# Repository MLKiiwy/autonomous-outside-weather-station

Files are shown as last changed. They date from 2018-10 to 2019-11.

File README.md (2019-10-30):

# Autonomous outside weather station

Build a complete autonomous outside weather station that can stay for years without battery change in your garden.
The station communicate the weather data to your home server OR a web server.
You can at any time access the graphs and last sensors values, from a web interface (smartphone compatible).

Total estimated cost of the full station: 40 euros.

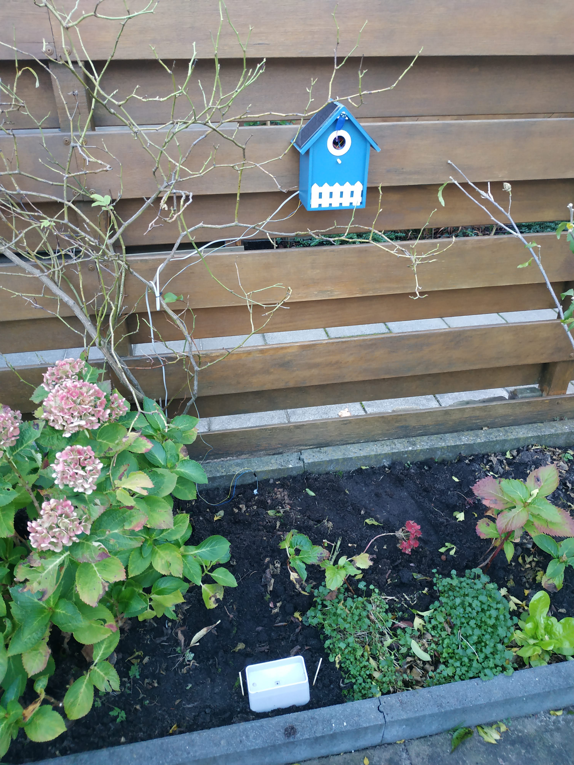
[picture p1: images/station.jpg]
Module Station setup outside

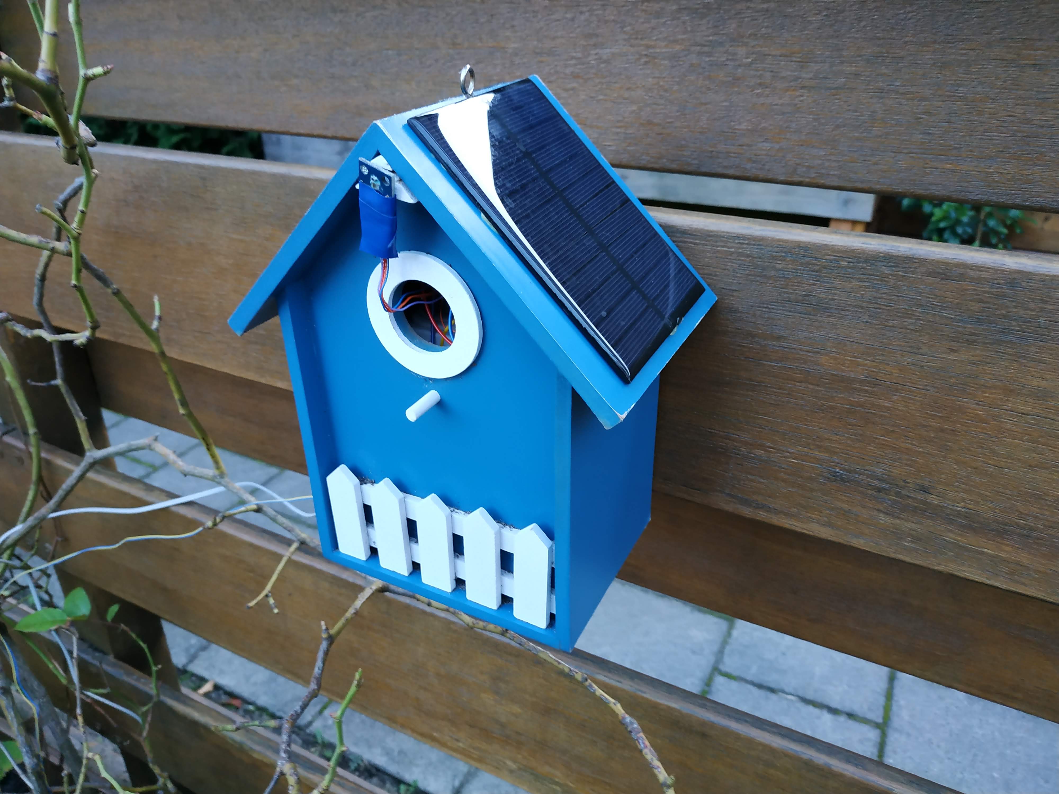
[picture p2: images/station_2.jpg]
Module Station setup outside 2


# Elements

Here is the detailed list of logical elements that compose the station.

## Station 

The station is build to be outside.
For that I use a small bird house.

Estimated cost: 5 euros

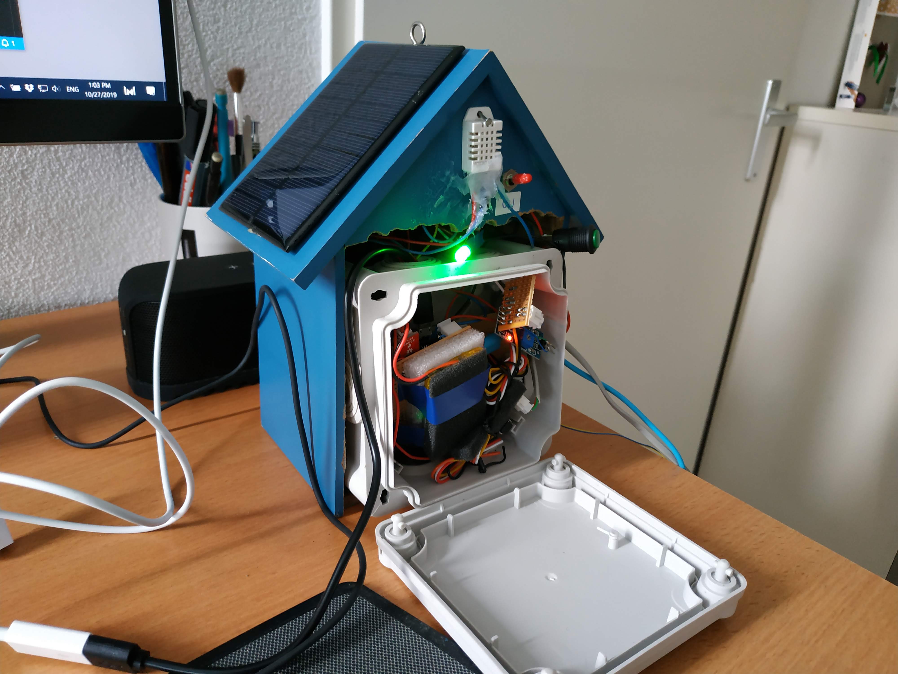
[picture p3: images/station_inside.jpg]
Module Station inside


## Main card with Wifi communication

The main card consist only of a ESP8266 + multiple connexions to each modules.
And for easy on/off, I have put a switch and a LED between the power module and the ESP8266.

Estimated cost: 3 euros

### Special Wire for DeepSleep

I use the deep sleep feature to save more power, and only take values every 10 minutes.

For that : Connect D0 to RST and use the deepSleep method in the code.

### Wifi Manager

You can install it from the library manager in arduino IDE
- [Wifi Manager] (https://github.com/tzapu/WiFiManager)

### MQTT

You can install it from the library manager in arduino IDE
- [PubSubClient] (https://github.com/knolleary/pubsubclient)

## Power module (Solar powered battery with level via I2C)

This module provide 4 outputs, 2 for power (+3.7V/GND) and 2 for battery level (I2C).
The battery is continuously charged by solar panel, with surcharge protection.
This module is autonomous and can be reuse in some other ESP8266 project.

[Detailed infos (Build instructions, components, sample code)](./elements/power_module/README.md)

## Rain counter module (Autonomous + low power consumption)  

This module provide a 5 pin interface: 2 for power (+3.7V/GND), 1 for waking up the module, 2 for communication (I2C)
This module should count the number of millimeter of rain. (precision 0.5 mm)
With a low power and complete autonomy even if main card is in sleep mode.

[Detailed infos (Build instructions, components, sample code)](./elements/rain_counter_module/README.md)

## Temperature and humidity sensor

This module you can read the outside temperature and humidity.
This module provide a 3 pin interface: 2 for power (3.7V/GND), 1 for reading the data.

[Detailed infos (Build instructions, components, sample code)](./elements/temperature_humidity_sensor/README.md)

## Atmospheric Pressure (+ station inside temperature and altitude)

This module provide atmospheric pressure, the temperature and the altitude.
This module is soldered directly on the main card with the ESP8266. (not autonomous, cannot be replace)

[Detailed infos (Build instructions, components, sample code)](./elements/barometric_sensor/README.md)

## Moisture sensor (or Hygrometer)

This module you can read the humidity of the soil with a probe.
This module provide a 4 pin interface (2 for power (3.7V/GND), 1 for waking up the module, 1 for com/reading)

[Detailed infos (Build instructions, components, sample code)](./elements/moisture_sensor/README.md)

## Light level sensor (Sun sensor)

This module you can read the level of the sun light (in lux)
This module provide a 4 pin interface: 2 for power (3.7V/GND), 2 for communication (I2C)

[Detailed infos (Build instructions, components, sample code)](./elements/light_level_sensor/README.md)

## Web Interface (Running on a home server)

I use Node-Red with the plugin for web UI.

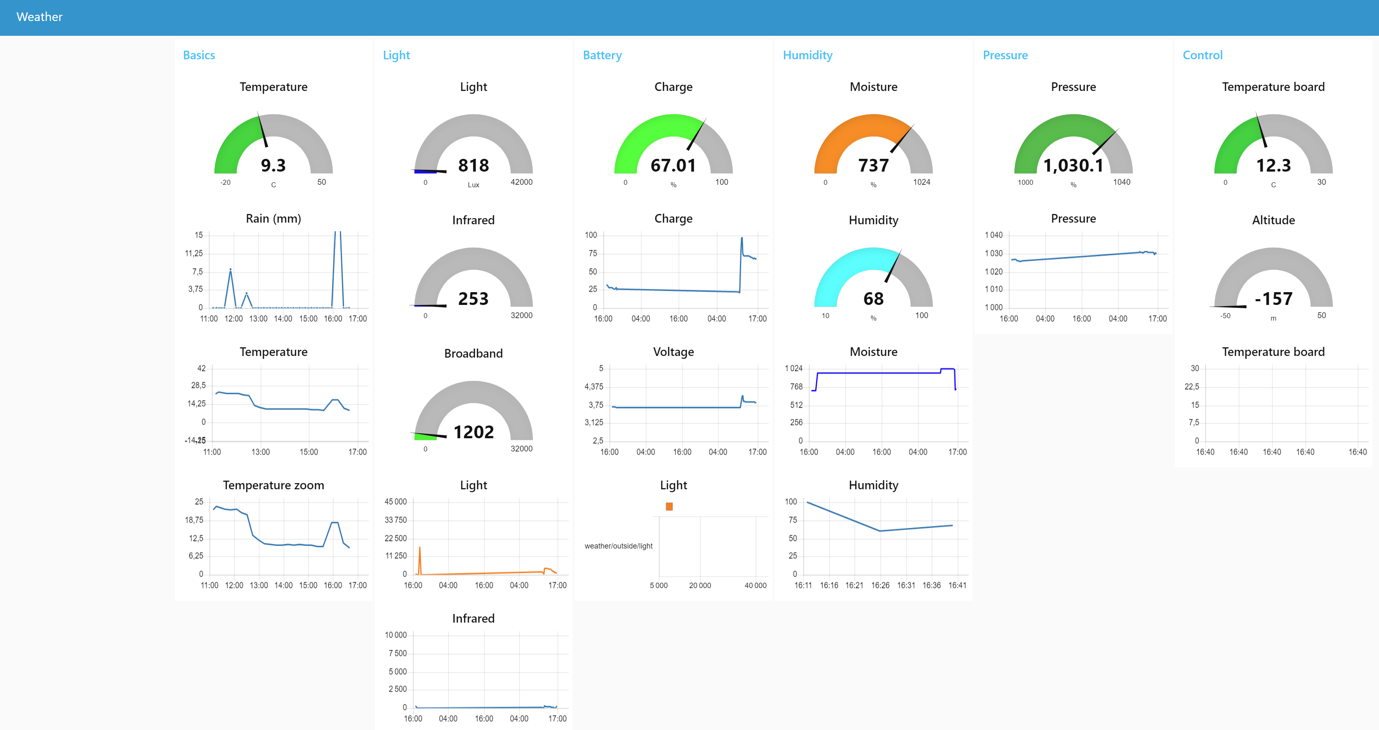
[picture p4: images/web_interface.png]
Module Web interface


## Install MQTT Broker on rapsberry Pi

See https://www.instructables.com/id/How-to-Use-MQTT-With-the-Raspberry-Pi-and-ESP8266/

```
sudo apt-get update
sudo apt-get upgrade
sudo apt-get install mosquitto -y
sudo apt-get install mosquitto-clients -y
```
## Final programs

See [Final program](./src/main.ino)

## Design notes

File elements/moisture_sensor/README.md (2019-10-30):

# Module : Soil Moisture Sensor

With this module you can read the humidity of the soil. 
For that we use a couple YL-38/YL-69.

## Corrosion / oxidation issue solution

If you use a soil moisture sensor before, if the sensor is powered for a long time, the probe is going to be oxided. 

So to avoid corrosion / oxidation we will power up the sensor only when reading, using a NPN Transistor (BC547) as switch.

## Images

### Module alone

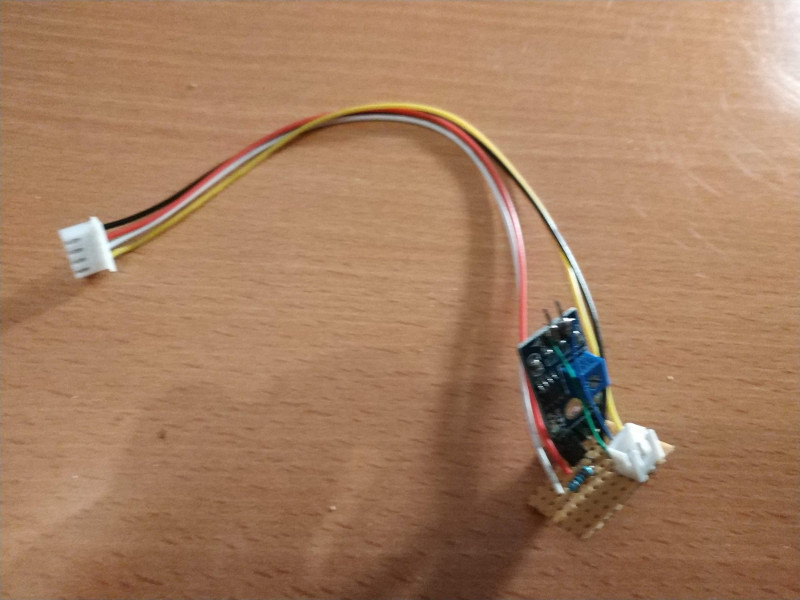
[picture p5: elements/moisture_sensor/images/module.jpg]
Module


### Module connected to all elements

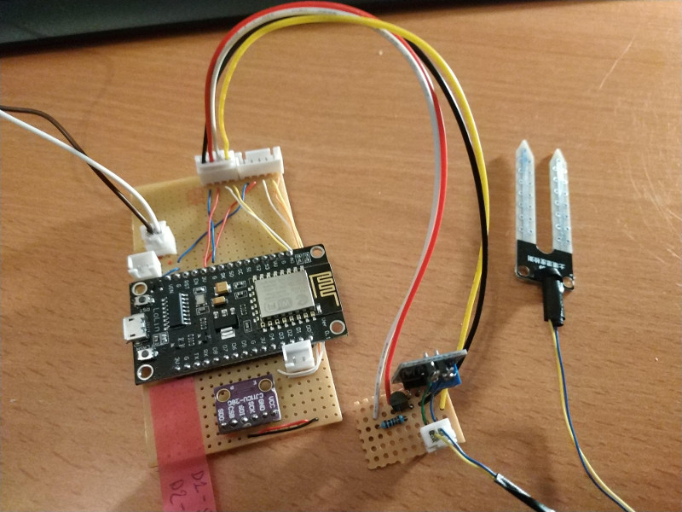
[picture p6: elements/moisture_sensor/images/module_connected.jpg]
Module connected


## Input

- 1 * 2 Pin for soil probe (YL-69)

## Output
- 1 * 4 Pin ( (Vin / GND / Reading Pin / Power On)

## Components 

- 1 hygrometer detection YL-69/YL-38 + (1euro)
- 1 transistor NPN BC547C (0.5 euro)
- 1 1 KOhm resistor ( 0.1 euro )

- some bakelite plate and thin wires (1 euro)

Estimated cost around 2.60 euros

## Schema

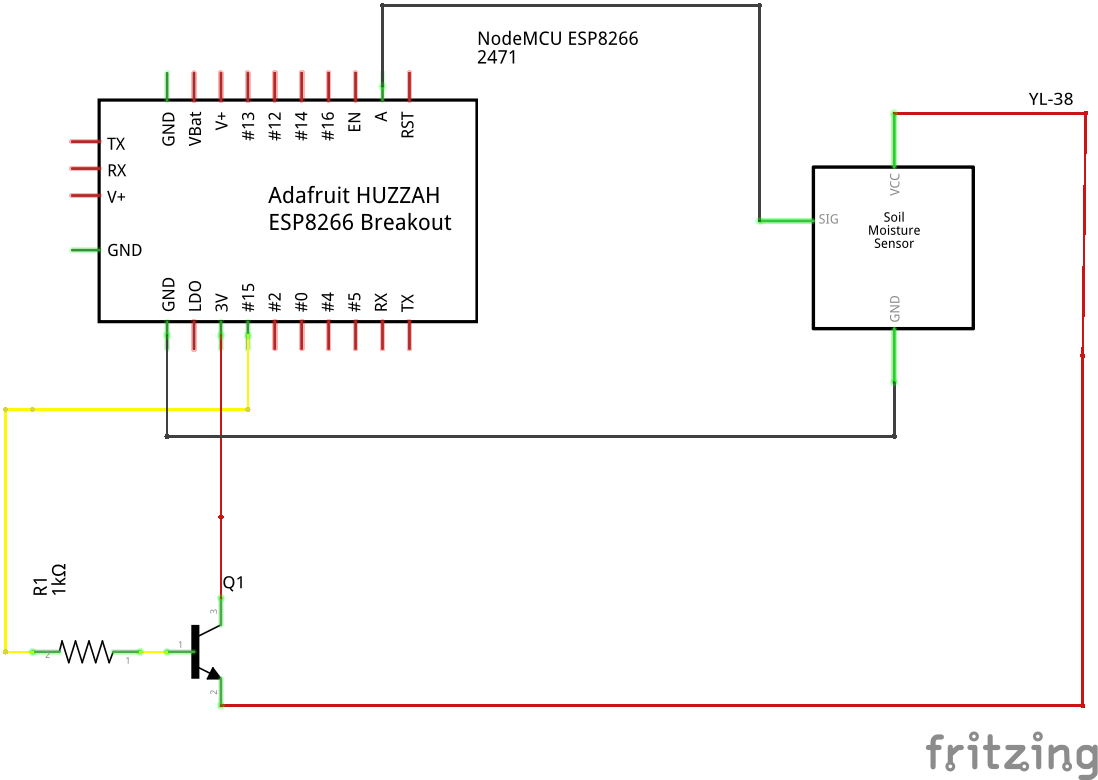
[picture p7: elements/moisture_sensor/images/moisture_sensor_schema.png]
Power module schema


## Required libraries 

[YL-38/YL-69 Sensor Arduino lib](https://github.com/jonson/arduino-moisture-sensor)

Execute [install.sh](./scripts/install.sh)

Or : 

```bash
git clone git@github.com:jonson/arduino-moisture-sensor.git
mv arduino-moisture-senso/libraries/ ~/Arduino/libraries
```

## Tests 

Use the code [Reading moisture](./read_moisture_sensor/read_moisture_sensor.ino) to test the module.
This code will just continuously ask the module the value of humidity of the soil.

### Issues

Don't use PIN D4 (GPIO 2) for the reading Pin.
There is an issue with this Pin if your ESP8266 goes to deepsleep, it remains the pin High ...
I use the GPIO 12 (D6) with no issue in deep sleep (The state remains low)

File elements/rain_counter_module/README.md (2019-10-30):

# Module : Rain counter

This module should count the number of millimeter of rain. 
With a low power and complete autonomy even if main card is in sleep mode.

## Images

### Module alone

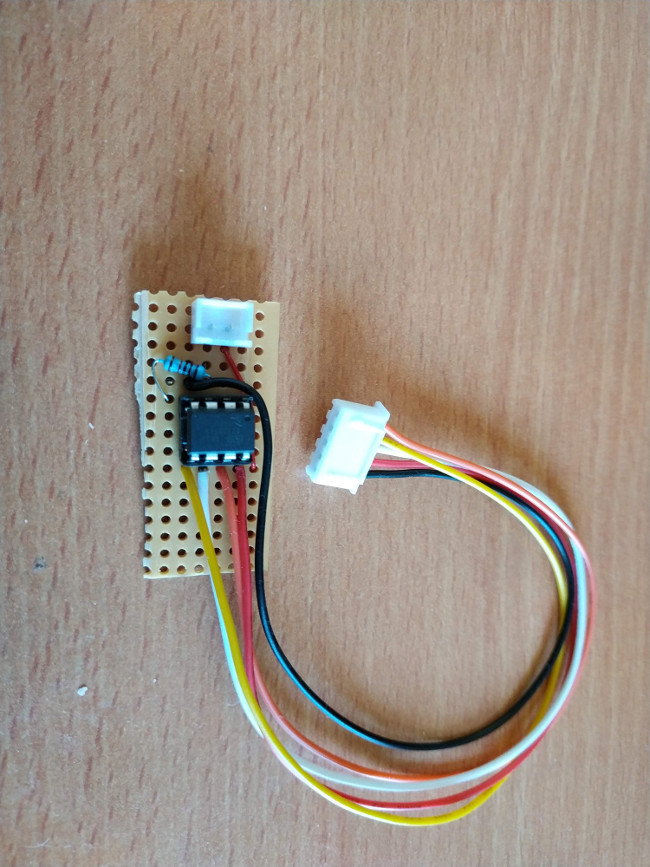
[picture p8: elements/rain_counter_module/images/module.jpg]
Module


### Module connected to all elements

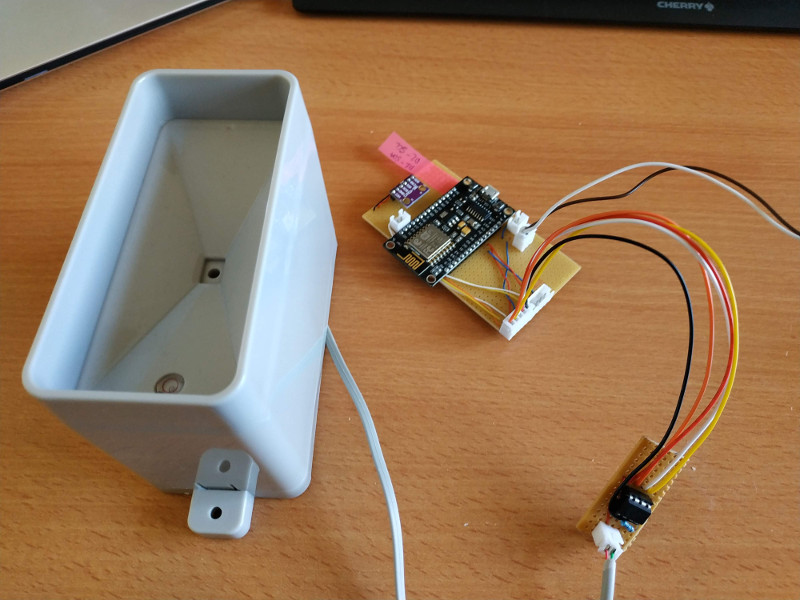
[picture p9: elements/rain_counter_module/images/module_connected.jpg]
Module connected


## Input

- 1 * 2 pin from rain collector

## Output

- 1 * 5 pin (Vin 3V, GND, 1 Wake up pin, 1 SDA, 1 SCL)

## Components 

- 1 rain collector (see [Rain meter/ rain gauge/ weather station spare part](https://www.aliexpress.com/item/1-pcs-of-spare-part-for-weather-station-for-rain-meter-to-measure-the-rain-volume/32793367115.html) - around 10 euros)
- 1 resistor (0.1 euros)
- 1 ATTiny85 (1 euro)

- some bakelite plate and thin wires (1 euro)

Estimated cost around 12.10 euros

## Using a pre-built rain collector

For that we use a pre-built rain collector from a commercial weather station.
This module is simply a rain collector that emit close a circuit, for each half millimeter collected. 
Its exactly the same behavior if you press a push button for every millimeter of rain.

Note: my rain collector has a surface of 0.0055 m2.
1mm of rain = 1Liter/m2 so here to have 1mm, you need 5.5ml.

During my test, I discover that my rain collector close the circuit twice for each millimeter, so the precision is of 0.5mm.

## Use a ATTiny as an autonomous module to count signal from rain collector

Because our station is going to sleep most of the time, we doesn't want to listen this signal from the ESP8266.

Instead we use a ATTiny85 as a "counter".
This tiny ship will listen this signal and increment a counter in its own memory.
Regulary the ESP8266 will ask the ATTiny the current value, and in the same time reset the value.

## Save more power => Put ATTiny85 in sleep mode and use an interuption

To save more power, we also use the "interupt" feature of the ATTiny85.
So when a signal is receive, the ATTiny count from the interuption function even in sleep mode (low power).
When the ESP8266 want to ask via I2C the rain count, before it put to high a wake up pin on the ATTiny and after send the I2C request.

## Schema

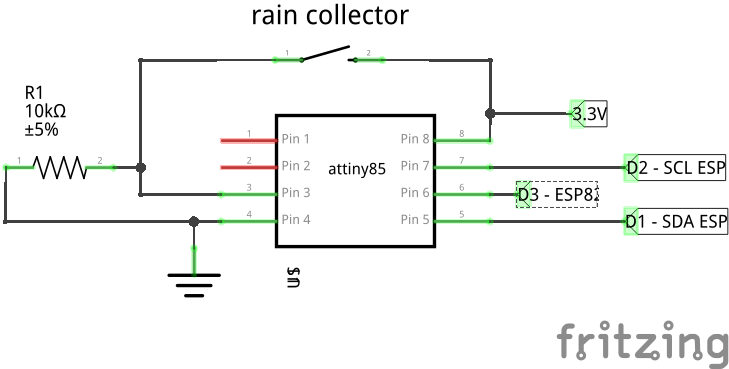
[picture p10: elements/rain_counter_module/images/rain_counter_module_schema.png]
Rain counter module schema


See also the pinout of the ATTiny85

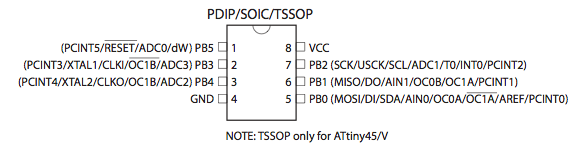
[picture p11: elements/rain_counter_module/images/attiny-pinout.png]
ATTiny85 pinout


## Required libraries 

Execute [install.sh](./scripts/install.sh) 

Or install them manually in your Arduino Lib directory.

### ATTiny85 support for Arduino

In board manager of Arduino find "ATTiny" lin and install it.

Required additional url in package manager : https://raw.githubusercontent.com/damellis/attiny/ide-1.6.x-boards-manager/package_damellis_attiny_index.json
More instructions [here](https://www.hackster.io/arjun/programming-attiny85-with-arduino-uno-afb829) .

### TinyWireS: AtTiny85 I2C Library

This [lib](https://github.com/nadavmatalon/TinyWireS) is used to make the ATTiny85 a slave on I2C.

Don't use the last version, there is an issue.
Use the one [here](./libs/TinyWireS).

## How to program the ATTiny85 ? 

See this good tutorial on [Hacktser](https://www.hackster.io/arjun/programming-attiny85-with-arduino-uno-afb829) 
I did exactly the same, I recommend to build a shield for programming the ATTiny85 with a "ZIF Socket".

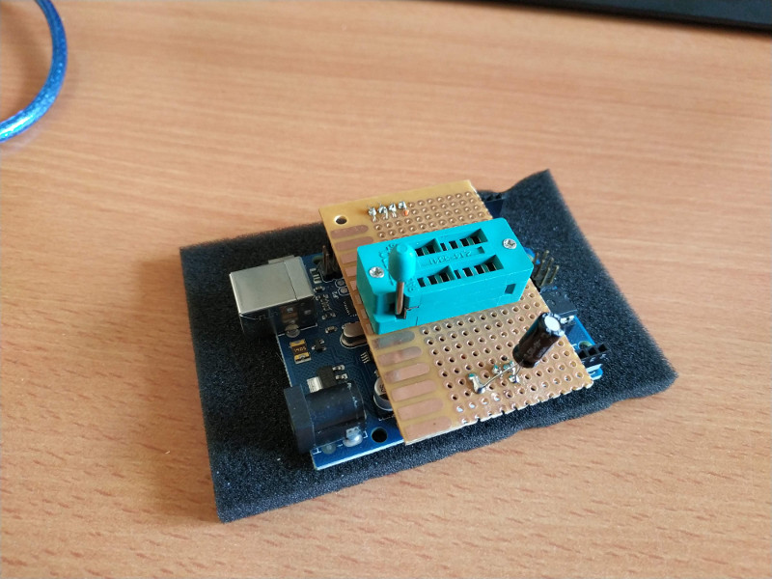
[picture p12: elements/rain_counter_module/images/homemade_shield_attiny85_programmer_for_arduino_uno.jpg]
Homemade ATTiny85 programmer shield for Arduino Uno


## Tests and development

For doing this module, I did a lot of small steps to test how to use the ATTiny85.
You can see all this step in order in the [./src](./src) folder.

### 1 - Try just to program the ATTiny85 with Arduino UNO + homemade shield

A simple program to blink the a LED.

### 2 - Do a communication with I2C between Arduino UNO and ATTiny85

Increase internal variable and return its value on each Arduino I2C request.

### 3 - Listen Interupt pin to count on ATTiny

### 4 - Interupt count + I2C communication 

### 5 - Interupt count + sleep + I2C Communication (Final ATTiny program)

### 6 - Final example using ESP8266 instead of Arduino Uno

## Issue with rain count not corresponding to number of closing on the rain collector

There is a difference between the number of tap of the rain collector, and what give the ATTiny85.
After several measure, I have decide to apply this formula to get the closest right value:

```c
ceil(value /10)
```

Of course it's an hack, I suppose the signal when the collector close the circuit create some "Jumps".
A way to fix it will be to clear the signal, maybe with a capacitor?

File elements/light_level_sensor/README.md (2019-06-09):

# Module : Light level sensor

With this module you can know the level of light. 
Usefull if you couple this data with the level of the power module, you can see normally when the solar panel are the most efficient.
For that we use a TSL2561 sensor.

## Images

### Module alone

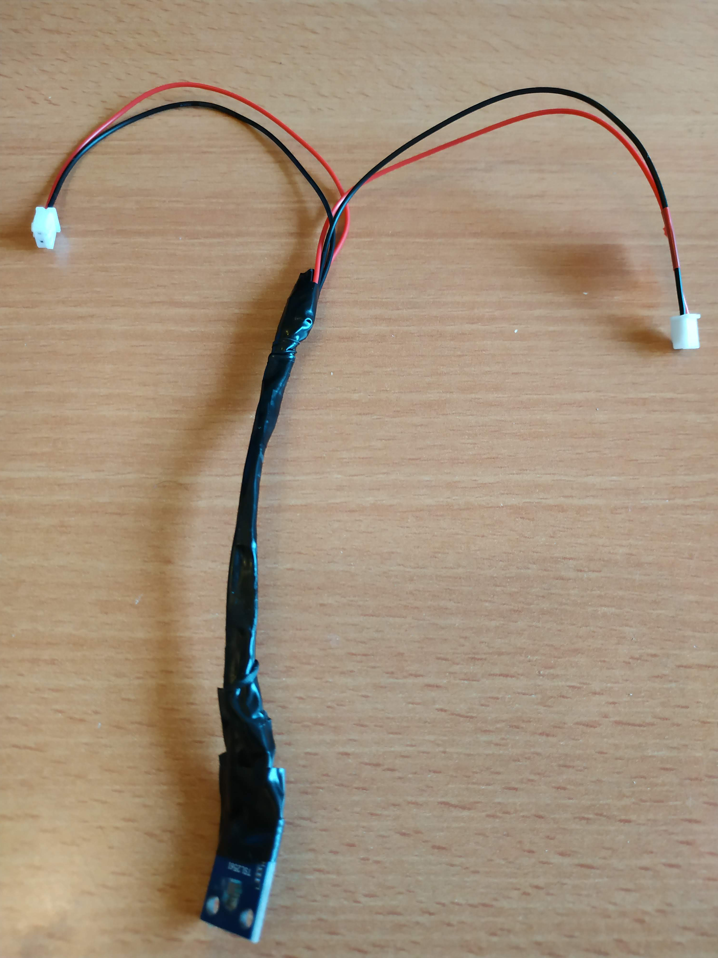
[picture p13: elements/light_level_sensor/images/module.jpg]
Module


### Module connected to all elements

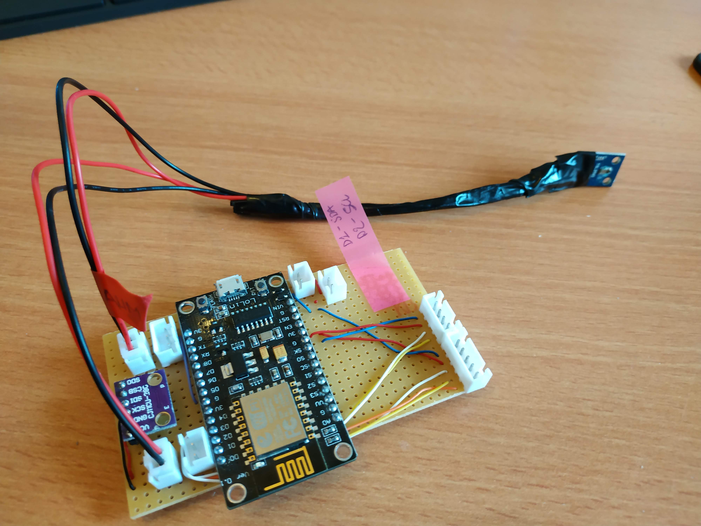
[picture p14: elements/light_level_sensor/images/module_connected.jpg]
Module connected


## Output

- 1 * 2 Pin ( (Vin 3.3v / GND)
- 1 * 2 Pin ( (SDA / SCL)

## Components

- 1 sensor TSL2561

Estimated cost around 2 euro

## Schema

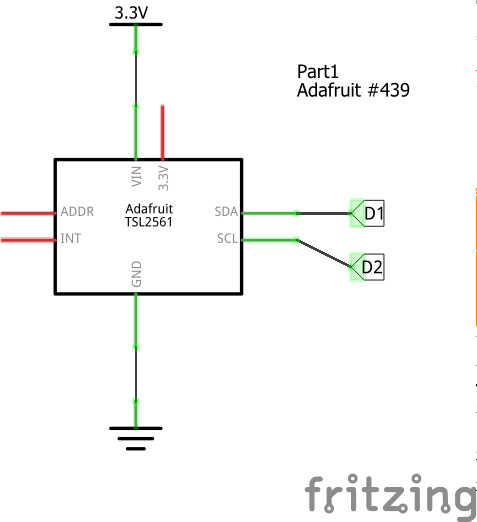
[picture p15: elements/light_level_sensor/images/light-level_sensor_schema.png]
Light level sensor


## Required libraries 

You can install it from the library manager in arduino IDE
- [Adafruit Unified Sensor] (https://github.com/adafruit/Adafruit_Sensor)
- [Adafruit TSL2561 (by Adafruit)](https://github.com/adafruit/Adafruit_TSL2561)

## Tests 

Use the code [Reading light level](./read_light-level_sensor.ino) to test the module.
This code will just continuously ask the module the value of the light level.

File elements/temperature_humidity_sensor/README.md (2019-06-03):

# Module : Temperature and humidity sensor

With this module you can read the temperature and humidity of the external air.
For that we use a DHT22 sensor.

## Images

### Module alone

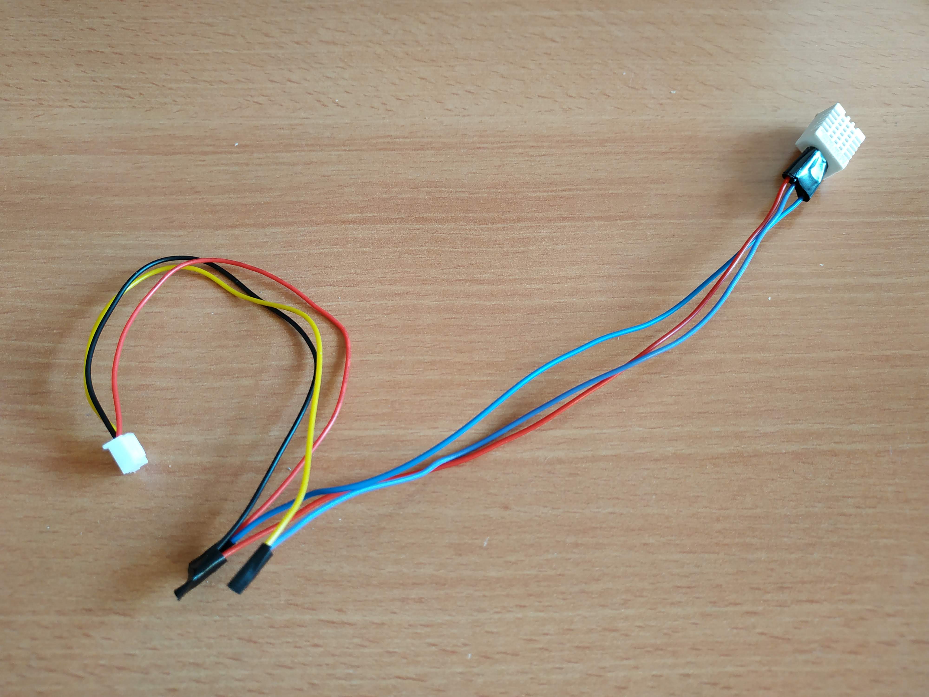
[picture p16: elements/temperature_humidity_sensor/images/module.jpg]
Module


### Module connected to all elements

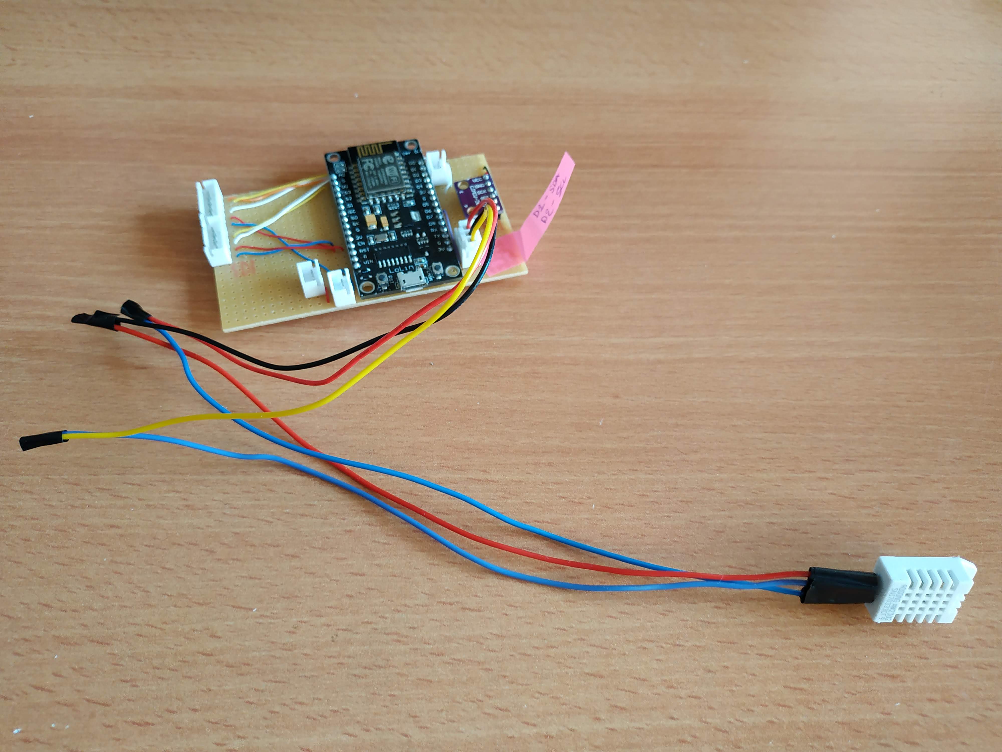
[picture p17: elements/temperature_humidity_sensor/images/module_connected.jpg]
Module connected


## Output

- 1 * 3 Pin ( (Vin / GND / Reading Pin )

## Components

- 1 sensor DHT22

Estimated cost around 2.50 euros

## Schema

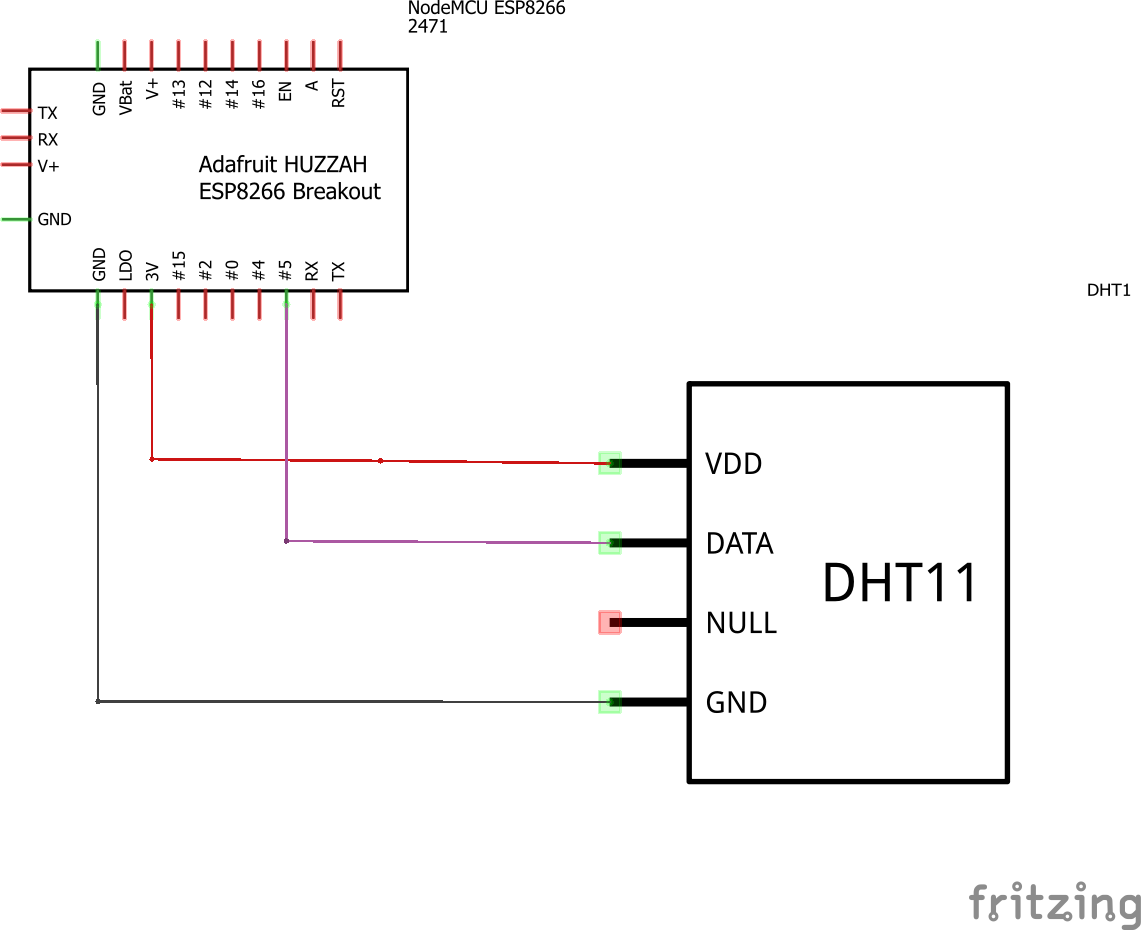
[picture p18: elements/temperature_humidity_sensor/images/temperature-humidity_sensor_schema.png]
Temperature and humidity sensor


## Required libraries 

You can install it from the library manager in arduino IDE
- [Adafruit Unified Sensor] (https://github.com/adafruit/Adafruit_Sensor)
- [DHT sensor library (by Adafruit)](https://github.com/adafruit/DHT-sensor-library)

## Tests 

Use the code [Reading temperature and humidity](./read_temperature_humidity_sensor.ino) to test the module.
This code will just continuously ask the module the value of temperature and humidity.

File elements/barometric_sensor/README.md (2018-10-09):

# Module : Atmospheric Pressure (+Temperature and altitude sensor)

With this module you can know the atmospheric pressure, the temperature and the altitude.

We use a BMP280 sensor connected on I2C.
Because we have another module for temperature with a better precision, we are going to put this one inside the weather station.
So the temperature will be the "inside" temperature around the ESP core.

## Good guide

See a good guide from adafruit here : https://learn.adafruit.com/adafruit-bmp280-barometric-pressure-plus-temperature-sensor-breakout/overview

## Warning : if you use a clone of the "adafruit" BMP280 sensor

If like me, you use a clone (chinese) version of the BMP280 sensor, you may have a different I2C address for the component.
Normally the adafruit BMP280 use the address "0x77" as you can see here in the lib : https://github.com/adafruit/Adafruit_BMP280_Library/blob/master/Adafruit_BMP280.h#L37
In my case the address is : 0x76

To find your address, use an I2C scanner on the ESP8266 : [tools/i2c_scanner](../../tools/i2c_scanner)
After this operation, I simply change the address use by the library by doing this : 

```c
#define BMP280_I2C_ADDRESS 0x76

// ....

void initBarrometricSensor() {
  if (!bmp.begin(BMP280_I2C_ADDRESS)) {  
    Serial.println("Could not find a valid BMP280 sensor, check wiring!");
  }
}

```

## Images

### Module directly wired to the ESP8266

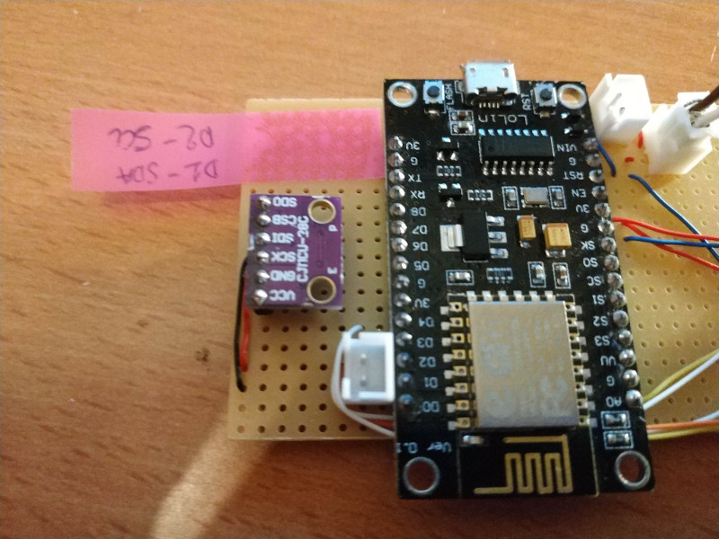
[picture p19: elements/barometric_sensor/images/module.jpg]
Module


## Components 

- 1 BMP280 (0.85 euro)

## Schema

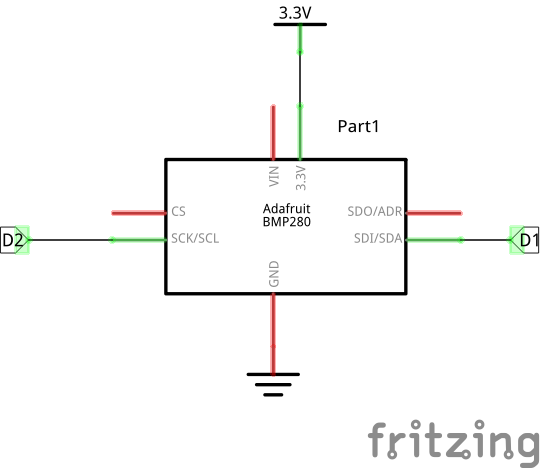
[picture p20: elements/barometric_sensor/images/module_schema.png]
BMP280 connection


## Required libraries 

- Search in arduino IDE the library "Adafruit Unified Sensor" And "Adafruit BMP280 Library" and install them.

## Tests 

Use the code [Basic reading BMP280](./basic_reading_bmp280_from_esp8266/basic_reading_bmp280_from_esp8266.ino) to test the module.
This code will just continuously ask the module the value of pressure, temperature and altitude.

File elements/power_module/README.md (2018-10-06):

# Module : Power system

This module should power our station (3.7V) and give some information about the battery level.
To charge the battery, we can plug a USB cable or put one or two solar panels. 
The idea is to use only solar panel all the time to continuously charge the battery. (full autonomy)

We also put a switch button between the ESP8266 and the power module, so we can easily restart our station.

## Images

### Module alone

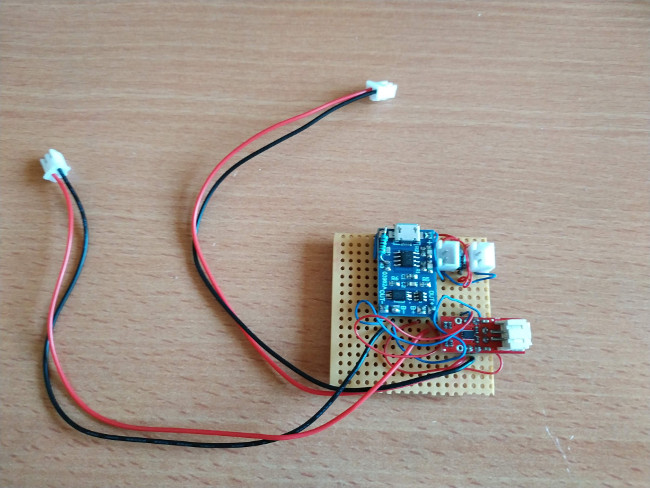
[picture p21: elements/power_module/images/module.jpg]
Module


### Module connected to all elements

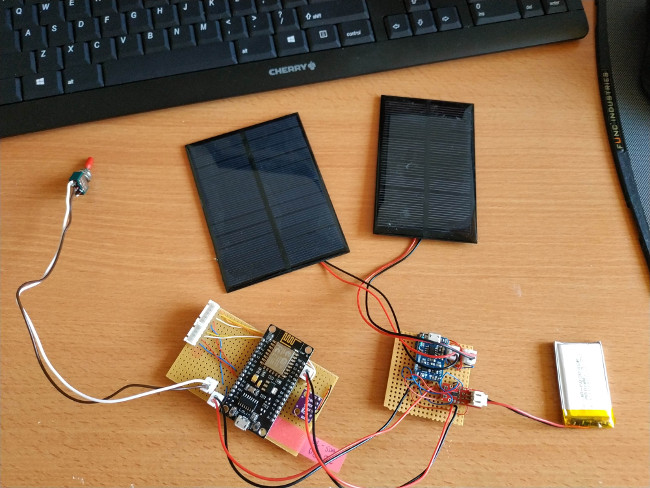
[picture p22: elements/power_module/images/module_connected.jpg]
Module connected


## Input

- 2 * 2 Pin for solar panels
- 1 micro usb for charging only
- 1 * 2 mini pin for a Lipo Battery

## Output
- 1 * 2 Pin 3.7V Power (Vin + GND)
- 1 * 2 Pin I2C battery level

## Components 

- 2 solar panels 5V 1.25W 250mA 110x70mm (4 euros)
- 1 switch button (0.5 euro)
- 1 TP4056 Charger module (with dual protection very important) [modified] (0.28 euro)
- 1 1.5 KOhm resistor ( 0.1 euro )
- 1 battery fuel gauge module MAX17043 (2.3 euros)
- 1 Diode 1N4007 (0.1 euro)
- 1 battery Lipo 800mah (2.5 euros)

- some bakelite plate and thin wires (1 euro)

Estimated cost around 10.78 euros

## Adapt TP4056 to our battery

We need to replace the command resistor of TP4056, because the default resistor is for a 1000mah battery.
Follow the [datasheet](https://dlnmh9ip6v2uc.cloudfront.net/datasheets/Prototyping/TP4056.pdf), to know the new resistor value for a 800mah battery:

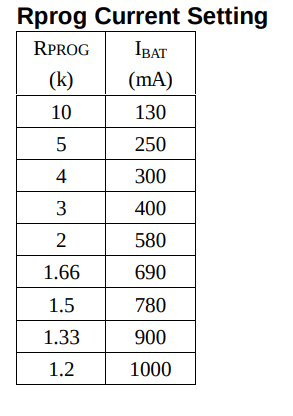
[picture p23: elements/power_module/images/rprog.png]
Rprog values


So we need to remove "R3" resistor

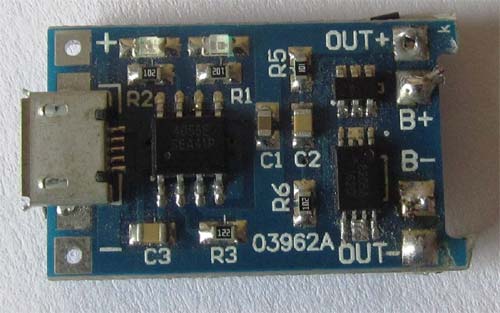
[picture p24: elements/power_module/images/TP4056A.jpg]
TP4056A


And put a new one like this : (you can put one side directly to GND)

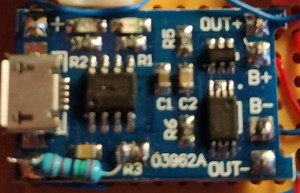
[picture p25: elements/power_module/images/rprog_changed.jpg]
Rprog changed


## Schema

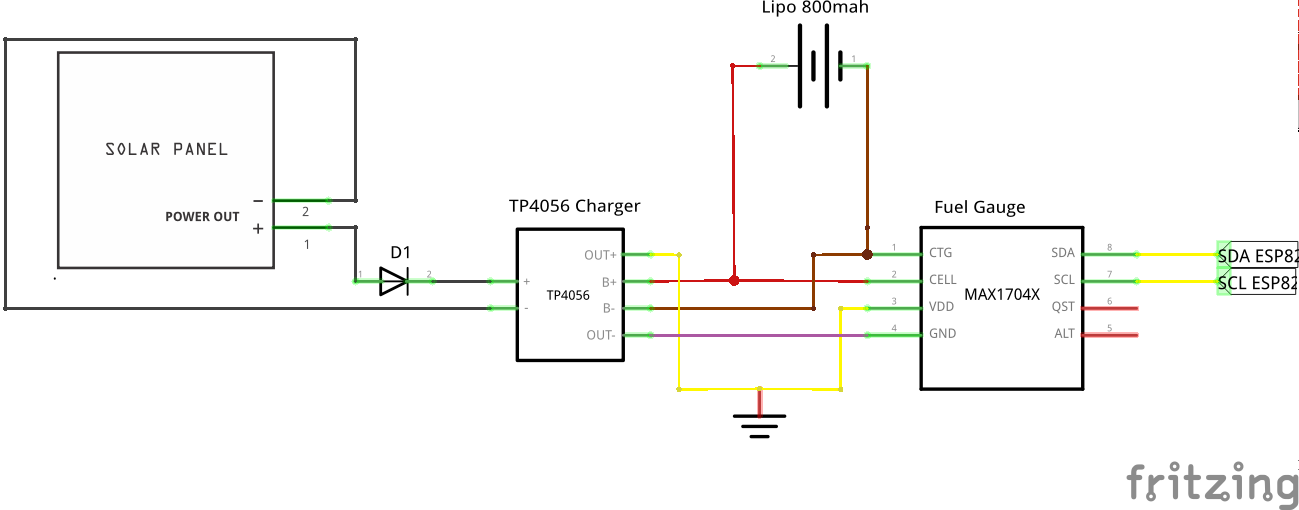
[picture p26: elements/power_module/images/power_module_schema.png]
Power module schema


## Required libraries 

[MAX17043 Library](https://github.com/lucadentella/ArduinoLib_MAX17043)

Execute [install.sh](./scripts/install.sh)

Or : 

```bash
cd ~/Arduino/libraries
git clone git@github.com:lucadentella/ArduinoLib_MAX17043.git
```

## Tests 

Use the code [Reading battery level](./reading_battery_level/reading_battery_level.ino) to test the module.
This code will just continuously ask the battery level and voltage to the module.

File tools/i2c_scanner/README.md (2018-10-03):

# I2C Scanner

Here you can find a code, to execute an I2C Scanner on your ESP8266.

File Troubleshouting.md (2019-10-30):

# How to program ESP8266 Module in Arduino IDE ? 

## IDE Config

For development you need:
- [Arduino IDE](https://www.arduino.cc/en/Main/Software) If on windows install it manually not from windows store
- Visual Studio code with Arduino extension, should work out of the box

## Install support for esp8266 in Arduino

Open the board manager in settings
Search for **esp8266** by ESP8266 and install it.

See https://github.com/esp8266/Arduino for more details

## Select Node MCU 1.0 in board manager

- Select : Node MCU 1.0

## Compile and use a particular file

See the settings of VSCode extension in .vscode/arduino.json, you can only have one .ino file set.

## Problem: cannot upload a new program to ESP8266

It's due to the deepsleep (pin wired for deep sleep)

So in case of 
```
Connecting........_____....._____....._
```

Press RST during the connection and it will continue the upload.

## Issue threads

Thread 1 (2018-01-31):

Use interruptions on ATTiny85

MLKiiwy, 2018-01-31:
Control a simple LED with interruptions :
- store the LED status in a variable
- use this status in the main loop to control an output PIN and switch the LED

Closed 2018-10-09.

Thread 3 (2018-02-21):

Build power system (using Battery + Solar panel)

MLKiiwy, 2018-02-21:
# Description
The power system need to deliver ~5V output
So we can plugin the value directly to our ATTiny + ESP8266 Node MCU

The power system will also have a I2C interface, so we can ask the % of charge of the battery.

In input, we will have the possibility to plug two solar panel in parallel.
And a Lipo Battery.

## Interface
- 2 x 2 pin input for solar panel
- 1 x 2 pin input for battery
- 1 x 4 pin output for I2C + 5V/GND pins

MLKiiwy, 2018-02-21:
# Build a 3.3V voltage regulator :
https://www.youtube.com/watch?v=J66_8P043ko
- HT7333-A.
- 1 1000uF
- 1 100nF

MLKiiwy, 2018-02-21:
# ATTiny input voltage

Check datasheet : http://html.alldatasheet.com/html-pdf/163120/ATMEL/ATTINY85-20PU/156/1/ATTINY85-20PU.html
And http://andybrown.me.uk/2010/11/07/an-introduction-to-the-attiny854525/

But normally we can use directly the input from the battery.
So for me, no need of a regulator or a DC-DC converter on the power system.

We can assume that 4.2V output is enough !

MLKiiwy, 2018-02-21:
https://www.addicore.com/TP4056-Charger-and-Protection-Module-p/ad310.htm

MLKiiwy, 2018-03-17:
For battery connector and level indicator :
https://www.sparkfun.com/products/10617

You need to put a 1,5 KOhm resistor on TP4056 (remove R3)
Check values here :
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

Closed 2018-10-06.

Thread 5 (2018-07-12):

Moisture sensor

MLKiiwy, 2018-07-12:
Using a couple YL-38 - YL-69

Goal :
- reading soil moisture/humidity
- have low comsomption / low oxidation / corrosion due (when you let the sensor always powered) -> Use a transistor to switch On/Off the sensor

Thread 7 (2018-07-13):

Barometric and inside temperature sensor

MLKiiwy, 2018-07-13:
Use a BMP280
https://learn.adafruit.com/adafruit-bmp280-barometric-pressure-plus-temperature-sensor-breakout/arduino-test

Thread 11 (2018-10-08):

Use another lib for reading battery level

MLKiiwy, 2018-10-08:
We can use also : [MAX17043 Library](https://github.com/awelters/LiPoFuelGauge)

Seems there is some nice built in functions on the MAX17043, like some alert for the battery low level.

But right now, when I try to use them, the communication was not working.

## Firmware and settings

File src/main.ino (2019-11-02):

#include <ESP8266WiFi.h>
#include <math.h>

// Everything required for WifiManager
#include <DNSServer.h>
#include <ESP8266WebServer.h>
#include <WiFiManager.h>

// MQTT
#include <PubSubClient.h>

#include <Wire.h>
#include <SPI.h>

#include <Adafruit_Sensor.h>
#include <Adafruit_BMP280.h>
#include <Adafruit_TSL2561_U.h>

#include <MoistureSensor.h>

#include <MAX17043.h>

#include <DHT.h>
#include <DHT_U.h>

#define DELAY_BETWEEN_TWO_WIFI_CONNECT_IN_S 4

#define SLEEP_TIME_IN_S 900

#define BMP280_I2C_ADDRESS 0x76

//Change the "1050.35" to your city current barrometric pressure (https://www.wunderground.com)
#define CURRENT_CITY_BAROMETRIC 1011 // Amsterdam

// I2C Configuration
// SDA (=SDI) ; SCL (=SCK)
#define SDA_I2C 5 // D1
#define SDL_I2C 4 // D2

#define MOISTURE_SENSOR_SWITCH 12 // D6
#define MOISTURE_SENSOR_ANALOG_READ A0 // A0
#define NUM_READINGS 50
#define DELAY_AFTER_MOISTURE_SENSOR_POWER_UP_IN_MS 2000

#define ATTINY_I2C_ADDRESS 0x04
#define ATTINY_WAKEUP_PIN 0 // D3 - GPIO0

#define DHT22_DATA 14     // D5, Pin which is connected to the DHT sensor.
#define DHTTYPE DHT22     // DHT 22

// Define MQTT topics
const char* TOPIC_TEMPERATURE = "weather/outside/temperature";
const char* TOPIC_PRESSURE = "weather/outside/pressure";
const char* TOPIC_ALTIMETER = "weather/outside/altimeter";
const char* TOPIC_CHARGE = "weather/outside/charge";
const char* TOPIC_VOLTAGE = "weather/outside/voltage";
const char* TOPIC_HUMIDITY = "weather/outside/humidity";
const char* TOPIC_LIGHT = "weather/outside/light";
const char* TOPIC_INFRARED = "weather/outside/infrared";
const char* TOPIC_BROADBAND = "weather/outside/broadband";
const char* TOPIC_MOISTURE = "weather/outside/moisture";
const char* TOPIC_RAIN = "weather/outside/rain";
const char* TOPIC_TEMPERATURE_BOARD = "weather/outside/temperature_board";

Adafruit_BMP280 bmp; // BMP 280 (I2C)
Adafruit_TSL2561_Unified tsl = Adafruit_TSL2561_Unified(TSL2561_ADDR_FLOAT, 12345);
MoistureSensor ms(MOISTURE_SENSOR_ANALOG_READ, NUM_READINGS);
MAX17043 batteryMonitor;  // Fuel gauge
DHT_Unified dht(DHT22_DATA, DHTTYPE);

WiFiManager wifiManager;

// MQTT
const char* mqtt_server = "192.168.1.12";
WiFiClient espClient;
PubSubClient mqttClient(espClient);

// Barometric sensor
float pressure;           //To store the barometric pressure (Pa)
float temperatureInside;  //To store the temperature (oC)
int altimeter;            //To store the altimeter (m) (you can also use it as a float variable)

// Light sensor
uint16_t light = 0;
uint16_t broadband = 0;
uint16_t infrared = 0;

// Moisture sensor
float moistureSensorLastValue = 0;

// Battery infos
float cellVoltage;
float stateOfCharge;

// Rain gauge
uint16_t rainGaugeRawLastValue = 0;
uint16_t rainGaugeLastValue = 0;

// Temperature and humidity
float temperature;
float humidity;

int deepSleepTime;

void readBMP280() {
  // From BMP280 Barometric sensor
  pressure = bmp.readPressure();
  temperatureInside = bmp.readTemperature();
  altimeter = bmp.readAltitude(CURRENT_CITY_BAROMETRIC);
}

void initBarrometricSensor() {
  if (!bmp.begin(BMP280_I2C_ADDRESS)) {
    Serial.println("Could not find a valid BMP280 sensor, check wiring!");
  }
}

void readLightSensor() {
  sensors_event_t event;

  // Lux sensor
  tsl.getEvent(&event);
  if (event.light) {
    light = event.light;
  } else {
    light = 17000;
  }

  tsl.getLuminosity (&broadband, &infrared);
}

void initLightSensor() {
  if (!tsl.begin())
  {
    /* There was a problem detecting the TSL2561 ... check your connections */
    Serial.print("Ooops, no TSL2561 detected ... Check your wiring or I2C ADDR!");
  }

  tsl.enableAutoRange(true);            /* Auto-gain ... switches automatically between 1x and 16x */
  tsl.setIntegrationTime(TSL2561_INTEGRATIONTIME_13MS);      /* fast but low resolution */
}

void initMoistureSensor() {
  pinMode(MOISTURE_SENSOR_SWITCH, OUTPUT);
}

float readMoistureSensor() {
  digitalWrite(MOISTURE_SENSOR_SWITCH, HIGH);

  // let the sensor warm up, the initial readings are not very accurate
  delay(DELAY_AFTER_MOISTURE_SENSOR_POWER_UP_IN_MS);

  for (int i = 0; i < NUM_READINGS; i++) {
    ms.reset();
    ms.read();
    delay(1);
  }

  moistureSensorLastValue = ms.getSmoothedReading();
  ms.reset();

  digitalWrite(MOISTURE_SENSOR_SWITCH, LOW);

  return moistureSensorLastValue;
}

void readBatteryLevelSensor() {
  cellVoltage = batteryMonitor.getVCell();
  stateOfCharge = batteryMonitor.getSoC();
}

void initBatteryLevelSensor() {
  batteryMonitor.reset();
  batteryMonitor.quickStart();
}

void initRainGauge() {
  pinMode(ATTINY_WAKEUP_PIN, OUTPUT);
}

void readGauge()
{
  digitalWrite(ATTINY_WAKEUP_PIN, HIGH);
  Wire.requestFrom(ATTINY_I2C_ADDRESS, 1);

  while (Wire.available())
  {
    rainGaugeRawLastValue = Wire.read();
  }
  digitalWrite(ATTINY_WAKEUP_PIN, LOW);
  rainGaugeLastValue = ceil(rainGaugeRawLastValue / 10);
}

void readDHT22() {
  sensors_event_t event;

  dht.temperature().getEvent(&event);
  if (!isnan(event.temperature)) {
    temperature = event.temperature;
  }
  dht.humidity().getEvent(&event);
  if (!isnan(event.relative_humidity)) {
    humidity = event.relative_humidity;
  }
}

void initTempAndHumiditySensor() {
  dht.begin();
}

void initWifi() {
  // If can't find previous network, start in AP and wait config
  if (!wifiManager.autoConnect("AP-Weather-Station")) {
    Serial.println("failed to connect and hit timeout");
    //reset and try again, or maybe put it to deep sleep
    ESP.reset();
    delay(DELAY_BETWEEN_TWO_WIFI_CONNECT_IN_S * 1000);
  }
}

void initMqtt() {
  mqttClient.setServer(mqtt_server, 1883);

  if (!mqttClient.connected()) {
    reconnectMqttClient();
  }
}

void reconnectMqttClient() {
  // Loop until we're reconnected
  while (!mqttClient.connected()) {
    Serial.print("Attempting MQTT connection...");
    // Create a random client ID
    String clientId = "ESP8266Client-";
    clientId += String(random(0xffff), HEX);
    // Attempt to connect
    if (mqttClient.connect(clientId.c_str())) {
      Serial.println("connected");
    } else {
      Serial.print("failed, rc=");
      Serial.print(mqttClient.state());
      Serial.println(" try again in 5 seconds");
      // Wait 5 seconds before retrying
      delay(5000);
    }
  }
}

void debugSensorsValuesOnSerial() {
  Serial.print("Pressure = ");
  Serial.println(pressure);

  Serial.print("Temperature = ");
  Serial.println(temperatureInside);

  Serial.print("Altitude = ");
  Serial.println(altimeter);

  Serial.print("Light level (LUX) = ");
  Serial.println(light);

  Serial.print("Infrared = ");
  Serial.println(infrared);

  Serial.print("Broadband = ");
  Serial.println(broadband);

  Serial.print("Moisture = ");
  Serial.println(moistureSensorLastValue);

  Serial.print("Voltage = ");
  Serial.println(cellVoltage);

  Serial.print("Charge in percent = ");
  Serial.println(stateOfCharge);

  Serial.println("Read rain gauge value in half millimeter = ");
  Serial.println(rainGaugeLastValue);

  Serial.print("Temperature = ");
  Serial.println(temperature);

  Serial.print("Humidity = ");
  Serial.println(humidity);

  Serial.println("------------------------");
}

void readSensors() {
  readBMP280();
  readLightSensor();
  readMoistureSensor();
  readBatteryLevelSensor();
  readGauge();
  readDHT22();
}

void publishMqttMessages() {
  mqttClient.publish(TOPIC_PRESSURE, (char*) String(pressure).c_str());
  mqttClient.publish(TOPIC_TEMPERATURE_BOARD, (char*) String(temperatureInside).c_str());
  mqttClient.publish(TOPIC_ALTIMETER, (char*) String(altimeter).c_str());
  mqttClient.publish(TOPIC_LIGHT, (char*) String(light).c_str());
  mqttClient.publish(TOPIC_INFRARED, (char*) String(infrared).c_str());
  mqttClient.publish(TOPIC_BROADBAND, (char*) String(broadband).c_str());
  mqttClient.publish(TOPIC_MOISTURE, (char*) String(moistureSensorLastValue).c_str());
  mqttClient.publish(TOPIC_VOLTAGE, (char*) String(cellVoltage).c_str());
  mqttClient.publish(TOPIC_CHARGE, (char*) String(stateOfCharge).c_str());
  mqttClient.publish(TOPIC_RAIN, (char*) String(rainGaugeLastValue).c_str());
  mqttClient.publish(TOPIC_TEMPERATURE, (char*) String(temperature).c_str());
  mqttClient.publish(TOPIC_HUMIDITY, (char*) String(humidity).c_str());
}

void gotoDeepSleep() {

  // Optimization for avoid no battery
  deepSleepTime = SLEEP_TIME_IN_S;
  if (stateOfCharge < 60 && stateOfCharge >= 40) {
    deepSleepTime = SLEEP_TIME_IN_S * 2;
  } else if (stateOfCharge < 40 && stateOfCharge >= 30 ) {
    deepSleepTime = SLEEP_TIME_IN_S * 3;
  } else if (stateOfCharge < 30 && stateOfCharge >= 20) {
    deepSleepTime = SLEEP_TIME_IN_S * 5;
  } else if (stateOfCharge < 20) {
    deepSleepTime = SLEEP_TIME_IN_S * 10;
  }

  ESP.deepSleep(deepSleepTime * 1000000);
}

void setup() {
  initMoistureSensor();
  initRainGauge();

  Wire.begin(SDA_I2C, SDL_I2C);

  Serial.begin(115200);

  initBarrometricSensor();
  initLightSensor();
  initBatteryLevelSensor();
  initTempAndHumiditySensor();

  initWifi();

  initMqtt();

  mainLoop();

  gotoDeepSleep();
}

void mainLoop()
{
  mqttClient.loop();
  readSensors();
  debugSensorsValuesOnSerial();
  publishMqttMessages();
}

void loop() {
}

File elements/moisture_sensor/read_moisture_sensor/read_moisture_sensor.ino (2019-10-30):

#include <MoistureSensor.h>

#define MOISTURE_SENSOR_SWITCH 12 // D6
#define MOISTURE_SENSOR_ANALOG_READ A0 // A0
#define NUM_READINGS 50

#define DELAY_IN_S 5
#define DELAY_AFTER_MOISTURE_SENSOR_POWER_UP_IN_MS 2000

MoistureSensor ms(MOISTURE_SENSOR_ANALOG_READ, NUM_READINGS);

float moistureSensorLastValue = 0;

void setup()
{
  pinMode(MOISTURE_SENSOR_SWITCH, OUTPUT);

  Serial.begin(9600); // start serial for debug
  Serial.println("Starting");
  Serial.print("We are going to read moisture sensor value every ");
  Serial.print(DELAY_IN_S);
  Serial.println("s");
}

float readMoistureSensor() {
  digitalWrite(MOISTURE_SENSOR_SWITCH, HIGH);

  // let the sensor warm up, the initial readings are not very accurate
  delay(DELAY_AFTER_MOISTURE_SENSOR_POWER_UP_IN_MS);

  for (int i = 0; i < NUM_READINGS; i++) {
    ms.reset();
    ms.read();
    delay(1);
  }

  moistureSensorLastValue = ms.getSmoothedReading();

  digitalWrite(MOISTURE_SENSOR_SWITCH, LOW);

  return moistureSensorLastValue;
}

void loop() {
  Serial.print("Moisture = ");
  Serial.println(readMoistureSensor());

  delay(DELAY_IN_S * 1000);
}

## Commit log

2018-07-16 [#7 barometric sensor] init
2018-10-03 feat(power_system): add sample code for baeetry gauge
2018-10-06 feat(power_system): fix doc
    [power_module.fzz]
2018-10-06 feat(power_module): fix sample
2018-10-09 feat(rain_counter_module): fix doc
    [rain_counter_module.fzz]
2018-10-09 fix(doc): add doc for moisture and barometric module
    [module.fzz]
2019-06-03 feat(temperature-humidity-sensor): add module
    [esp8266-temperature-humidity-sensor-connection.fzz]
2019-06-09 feat(light-level-sensor): add module
    [esp8266-light-level-sensor-connection.fzz]
2019-11-02 fix(deep-sleep): if else was wrong
    [main.ino]
